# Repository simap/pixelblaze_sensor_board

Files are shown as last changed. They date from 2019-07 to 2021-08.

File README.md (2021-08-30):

Pixelblaze Sensor Expansion Board
-------------------

sensor board

* A microphone and signal processing with frequency magnitude data ranging from 37Hz-10KHz designed to work in very loud environments
* A 3-axis 16G accelerometer
* An ambient light sensor
* 5 analog inputs that can be used with potentiometers or other analog inputs

[For sale on Tindie](https://www.tindie.com/products/12158/)! Pick up this board and/or a Pixelblaze! Make cool sound-reactive LED things, or get one and hack the firmware!

soundmatrix

I hope you find this useful or interesting. Maybe you hack your board? I'd be stoked to hear about it! Roll your own? Great! Turn it into a robot brain? Awesome!

Shout out to Sparkfun, their boards were used in the initial prototype, and their Eagle files were really helpful!

Shout out to [https://github.com/pyrohaz/STM32F0-PCD8544GraphicAnalyzer](https://github.com/pyrohaz/STM32F0-PCD8544GraphicAnalyzer) which does similar FFT stuff with a similar processor, even shares the fixed point FFT code in common!

Non-Pixelblaze Usage
-------------------
Looking to use this with an Arduino or Teensy or something? You just need a free serial port at 115200 baud.

The protocol is fairly simple:

1. Each frame starts with "SB1.0" including a null character (6 bytes).
2. The frequency information follows, as 32 x 16-bit unsigned integers.
3. Then is the audio energy average, max frequency magnitiude, max frequency Hz, all 3 as 16-bit unsigned ints.
4. Next the accelerometer information as 3 x 16-bit signed integers.
5. The data from the Light sensor is next, as a single 16-bit unsigned integer.
6. Followed by the 5 x 16-bit analog inputs (12-bit resolution, shifted up to 16 bits)
7. Finally "END" including a null character (4 bytes).

License Information
-------------------
The hardware files are released under [Creative Commons ShareAlike 4.0 International](https://creativecommons.org/licenses/by-sa/4.0/) since the PCB is largely based off of Sparkfun boards with this license requirement.

Distributed as-is; no warranty is given.

The ElectroMage logo and wizard character is excluded from this license.

The software is released under The MIT License.

The MIT License

Copyright (c) 2018 Ben Hencke

Permission is hereby granted, free of charge, to any person obtaining a copy
of this software and associated documentation files (the "Software"), to deal
in the Software without restriction, including without limitation the rights
to use, copy, modify, merge, publish, distribute, sublicense, and/or sell
copies of the Software, and to permit persons to whom the Software is
furnished to do so, subject to the following conditions:

The above copyright notice and this permission notice shall be included in
all copies or substantial portions of the Software.

THE SOFTWARE IS PROVIDED "AS IS", WITHOUT WARRANTY OF ANY KIND, EXPRESS OR
IMPLIED, INCLUDING BUT NOT LIMITED TO THE WARRANTIES OF MERCHANTABILITY,
FITNESS FOR A PARTICULAR PURPOSE AND NONINFRINGEMENT. IN NO EVENT SHALL THE
AUTHORS OR COPYRIGHT HOLDERS BE LIABLE FOR ANY CLAIM, DAMAGES OR OTHER
LIABILITY, WHETHER IN AN ACTION OF CONTRACT, TORT OR OTHERWISE, ARISING FROM,
OUT OF OR IN CONNECTION WITH THE SOFTWARE OR THE USE OR OTHER DEALINGS IN
THE SOFTWARE.

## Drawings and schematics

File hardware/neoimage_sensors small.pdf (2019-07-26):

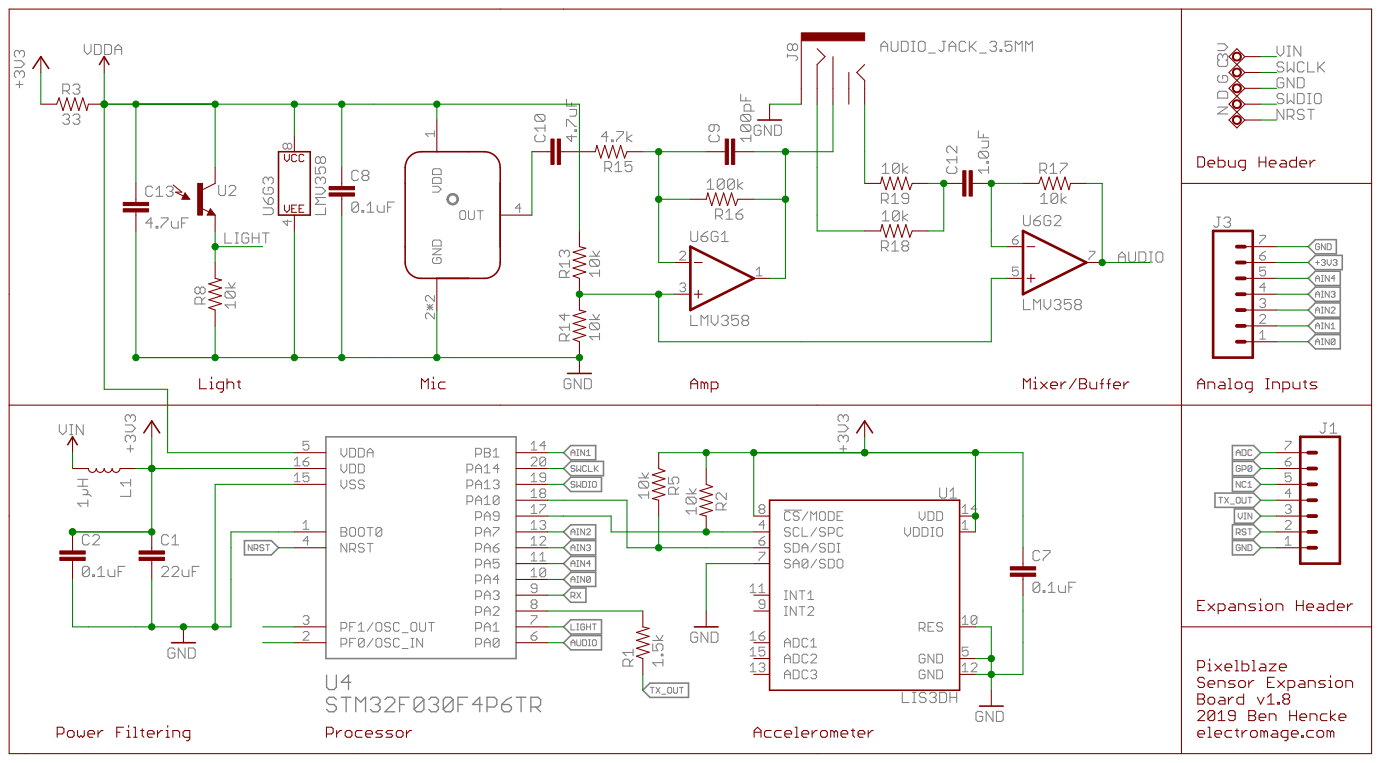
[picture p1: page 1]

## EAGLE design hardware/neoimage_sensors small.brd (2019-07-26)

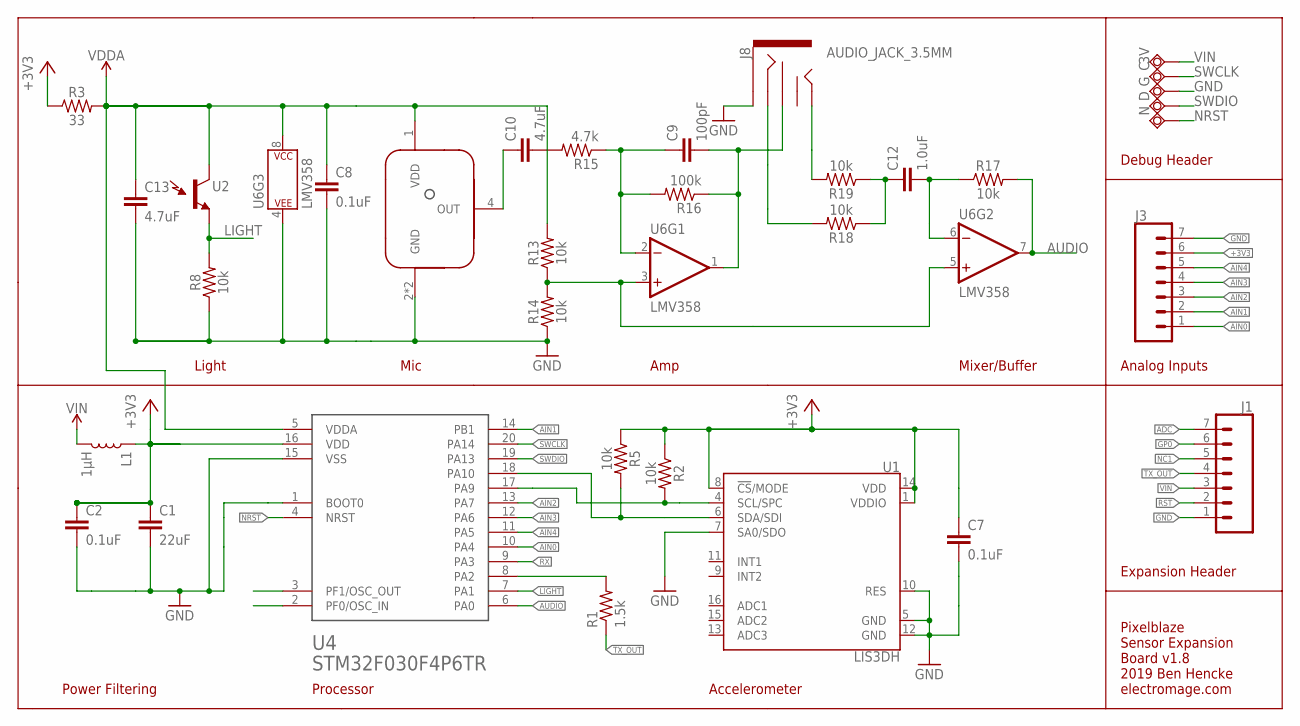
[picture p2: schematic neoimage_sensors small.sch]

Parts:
3V: TPSQTP18SQ; TP18SQ
C: TPSQTP18SQ; TP18SQ
C1: 22uF; 0805
C2, C7, C8: 0.1uF; 0603
C9: 100pF; 0603
C10, C13: 4.7uF; 0603
C12: 1.0uF; 0603
D: TPSQTP18SQ; TP18SQ
G: TPSQTP18SQ; TP18SQ
J1, J3: CONN_07LOCK; 1X07_LOCK
J8: AUDIO_JACK_3.5MM; AUDIO-JACK-KIT
L1: 1µH; 0805
N: TPSQTP18SQ; TP18SQ
R1: 1.5k; 0603
R2, R5, R8, R13, R14, R17, R18, R19: 10k; 0603
R3: 33; 0603
R15: 4.7k; 0603
R16: 100k; 0603
U1: LIS3DH; LGA-16-3X3
U2: LIGHT_SENSORALS; ALS-PT19
U4: STM32F030F4P6TR; TSSOP-20
U6: LMV358; SO08
U$3: MICROPHONE-MEMS; MICROPHONE-MEMS-3X3.75

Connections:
+3V3: C1.1, C2.1, C7.1, J3.6, L1.1, R2.1, R3.1, R5.1, U1.1 (VDDIO), U1.8 (!CS!/MODE), U1.14 (VDD), U4.16 (VDD)
ADC: J1.7
AIN0: J3.1, U4.10 (PA4)
AIN1: J3.2, U4.14 (PB1)
AIN2: J3.3, U4.13 (PA7)
AIN3: J3.4, U4.12 (PA6)
AIN4: J3.5, U4.11 (PA5)
AUDIO: R17.2, U4.6 (PA0), U6.7 (OUT)
GND: C1.2, C2.2, C7.2, C8.2, C13.2, G.TP, J1.1, J3.7, J8.SLEEVE, R8.1, R14.1, U1.5 (GND), U1.7 (SA0/SDO), U1.10 (RES), U1.12 (GND), U4.1 (BOOT0), U4.15 (VSS), U6.4 (P$V-), U$3.2 (GND), U$3.3 (GND)
GP0: J1.6
LIGHT: R8.2, U2.E (E1), U4.7 (PA1)
MICOUT: C9.2, J8.RSH, R16.1, U6.1 (OUT)
unnamed: C10.1, U$3.4 (OUT)
unnamed: C9.1, R15.1, R16.2, U6.2 (-IN)
unnamed: C10.2, R15.2
unnamed: R13.1, R14.2, U6.3 (+IN), U6.5 (+IN)
unnamed: C12.1, R18.1, R19.1
unnamed: C12.2, R17.1, U6.6 (-IN)
unnamed: J8.TIP, R19.2
unnamed: J8.RING, R18.2
NC1: J1.5
NRST: N.TP, U4.4 (NRST)
RST: J1.2
RX: U4.9 (PA3)
SCL: R5.2, U1.6 (SDA/SDI), U4.18 (PA10)
SDA: R2.2, U1.4 (SCL/SPC), U4.17 (PA9)
SWCLK: C.TP, U4.20 (PA14)
SWDIO: D.TP, U4.19 (PA13)
TX: R1.2, U4.8 (PA2)
TX_OUT: J1.4, R1.1
VDDA: C8.1, C13.1, R3.2, R13.2, U2.C (C1), U4.5 (VDDA), U6.8 (P$V+), U$3.1 (VDD)
VIN: 3V.TP, J1.3, L1.2

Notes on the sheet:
Expansion Header
Analog Inputs
Debug Header
Mic
Accelerometer
Processor
Light
Amp
Mixer/Buffer
Power Filtering
Pixelblaze Sensor Expansion Board v1.8 2019 Ben Hencke electromage.com

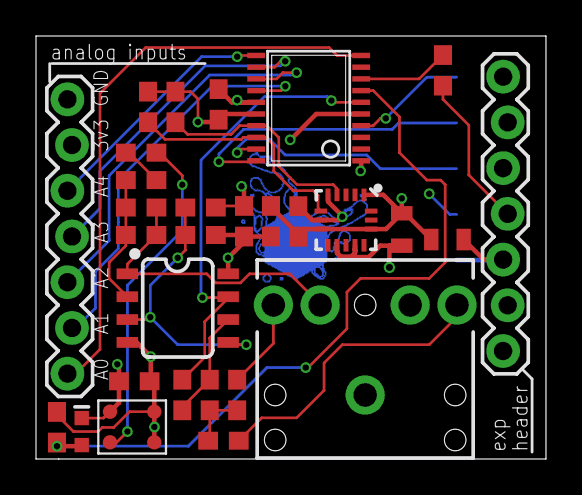
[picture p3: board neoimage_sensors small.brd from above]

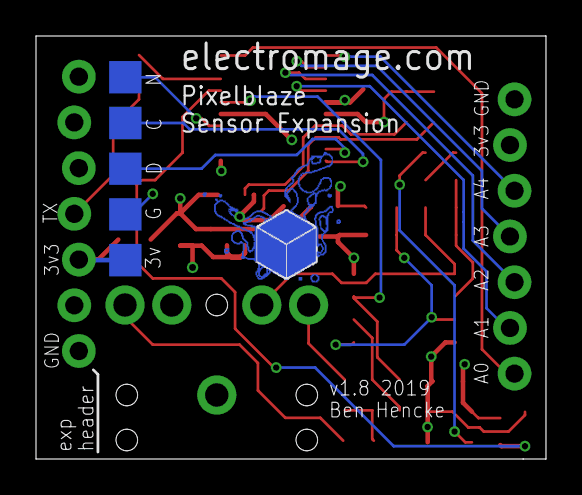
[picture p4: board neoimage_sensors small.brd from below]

Board: 4 copper layers, 28.3 x 23.5 mm, 35 parts (6 on the bottom side), 27 nets.

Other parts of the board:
U$4: ELECTRO_MAGE_PCB4_PIXEL_2#PNG

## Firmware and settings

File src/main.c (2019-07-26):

#include "main.h"


enum {
	IDLE, STARTING, SENDING_REG, READING, STOPPING, NEEDSRESET
} I2CMode = NEEDSRESET;


uint32_t audioAverage = 16384<<16;
volatile uint16_t adcBuffer[7]; //updated by DMA @ 20KHz
volatile int16_t accelerometer[3]; //updated by DMA
volatile uint32_t ms = 0; //updated by SysTick


//ping-pong buffer for main 20KHz audio
volatile bool readDone;
int readSide;
int readPos;
int16_t buffer[2][HIGH_N];

//circular buffer for low frequency stuff - we need to reuse parts of it and can afford the memory
//the 32 samples cover 1600 samples of the original audio
struct {
	int16_t circular[32];
	int16_t output[32];
	int head;
	//keep track of how many samples have passed through the filter to know when to sample from it
	int downSampleCounter;
	int32_t avg;
} bufferLowHz;

int main(void) {
	SysTick_Config(SystemCoreClock/1000); //tick interval 1ms
	initRcc();
	initTim1();
	initDma();
	initAdc();
	initGpio();
	initUart();
	initI2C();

	for (;;) {

		if (I2CMode == NEEDSRESET)
			initAccelerometer();

		//listen for message that the sample buffer is ready to process
		if (readDone) {
			readDone = false;

//			GPIO_WriteBit(GPIOB, GPIO_Pin_1, 1);

			//start polling the accelerometer now, it can run in the background while the FFT processes
			startAccelerometerPoll();

			//grab the side we're not currently writing to and do an FFT on it
			processSensorData(&buffer[!readSide][0], &bufferLowHz.output[0], adcBuffer, accelerometer);

//			GPIO_WriteBit(GPIOB, GPIO_Pin_1, 0);
		}

	}
}

void initRcc() {
	//enable adc, dma, uart, i2c, and gpio clocks
	RCC->AHBENR |= RCC_AHBENR_GPIOAEN | RCC_AHBENR_GPIOBEN | RCC_AHBENR_DMAEN;
	RCC->APB1ENR |= RCC_APB1ENR_I2C1EN;
	RCC->APB2ENR |= RCC_APB2ENR_ADC1EN | RCC_APB2ENR_TIM1EN | RCC_APB2ENR_USART1EN;

	//Start HSI14 RC oscillator for the ADC and wait for it
	RCC->CR2 |= RCC_CR2_HSI14ON;
	while (!(RCC->CR2 & RCC_CR2_HSI14RDY))
		;
}

void initTim1() {
	TIM1->CR2 |= TIM_CR2_MMS_1 | TIM_CR2_MMS_0; //output compare pulse - magic trigger needed for ADC
	TIM1->CR1 |= TIM_CR1_CEN | TIM_CR1_ARPE; // enable and auto-reload
	TIM1->ARR = 2399; //48mhz / 2400 = 20khz

	//Generate an update event to reload the Prescaler and the repetition countervalue immediately
	TIM1->EGR = TIM_EGR_UG;
}

void initAdc() {
	// set ADC_CR_ADCAL to start calibration and wait for it to clear
	ADC1->CR |= ADC_CR_ADCAL;
	while (ADC1->CR & ADC_CR_ADCAL)
		;
	//set ADC_CFGR1_CONT for continuous mode
	//set ADC_CFGR1_EXTEN = 01 for trigger on rising edge
	//set ADC_CFGR1_EXTSEL = 000 for TIM1_TRGO
	//set ADC_CFGR1_DMACFG = 1 for dma circular
	//set ADC_CFGR1_DMAEN = 1 to enable dma
	ADC1->CFGR1 = ADC_CFGR1_DMACFG | ADC_CFGR1_DMAEN | ADC_CFGR1_EXTEN_0;

	//set ADC_SMPR = 101 for 55cycle sample time
	ADC1->SMPR = 0b101;
	//set ADC_CHSELR bits to enable various channels (0, 1, 4, 5, 6, 7, 8)
	ADC1->CHSELR = ADC_CHSELR_CHSEL0 | ADC_CHSELR_CHSEL1 | ADC_CHSELR_CHSEL4 |
					ADC_CHSELR_CHSEL5 | ADC_CHSELR_CHSEL6 | ADC_CHSELR_CHSEL7 | ADC_CHSELR_CHSEL9;
	//set ADC_ADEN to enable adc and wait for ready
	ADC1->CR |= ADC_CR_ADEN;
	while (!(ADC1->ISR & ADC_ISR_ADRDY))
		;
	//set ADC_CR_ADSTART to start (will wait for external trigger in this mode)
	ADC1->CR |= ADC_CR_ADSTART;
}

void initGpio() {
	//select alternate function 1 (usart1) for pin 2 and 3 - on the stm23f040f4 it defaults to TIM15_CH1/TIM15_CH2
	GPIOA->AFR[0] |= 0b0001 << 8 | 0b0001 << 12;
	//select alternate function 4 (i2c1) for pin 9 and 10
	GPIOA->AFR[1] |= 0b0100 << 4 | 0b0100 << 8;
	//set a0, a1, a4, a5, a6, a7 and b1 to analog inputs
	//set a2, a3 as alternate mode (tx, rx) and a9, a10 as alt mode (i2c)
	GPIOA->MODER |= GPIO_MODER_MODER0 | GPIO_MODER_MODER1 |
			GPIO_MODER_MODER2_1 | GPIO_MODER_MODER3_1 | //set up a2 and a3 as alt function (usart1)
			GPIO_MODER_MODER4 | GPIO_MODER_MODER5 | GPIO_MODER_MODER6 | GPIO_MODER_MODER7 |
			GPIO_MODER_MODER9_1 | GPIO_MODER_MODER10_1; //set up a9 and a10 as alt function (i2c)

	GPIOB->MODER |= GPIO_MODER_MODER1;
//	GPIOB->MODER |= GPIO_MODER_MODER1_0; //output for scoping timings
}

void initUart() {
	USART1->BRR = 0x1A1; // example from manual for 115200 @ 48mhz
	//enable tx, and uart, leave everything else 0 for 8N1
	USART1->CR1 = USART_CR1_TE | USART_CR1_UE;
	//enable DMA for transmits
	USART1->CR3 |= USART_CR3_DMAT;
}

void initDma() {
	//configure DMA to read from ADC into a buffer
	DMA1_Channel1->CPAR = (uint32_t) (&(ADC1->DR)); //point dma to ADC data reg
	DMA1_Channel1->CMAR = (uint32_t) (adcBuffer); //point DMA to buffer memory
	DMA1_Channel1->CNDTR = 7; //count of transfers per circle
	//enable DMA_CCR_CIRC (circular) mode (so addresses reset when its done)
	//set DMA_CCR_MINC to incrememnt memory address
	//set DMA_CCR_MSIZE = 01 for 16 bit xfers to memory
	//set DMA_CCR_PSIZE = 01 for 16 bit xfers from perepheral
	//set DMA_CCR_TCIE for transfer complete interrupt
	DMA1_Channel1->CCR |= DMA_CCR_CIRC | DMA_CCR_MINC | DMA_CCR_MSIZE_0 | DMA_CCR_PSIZE_0 | DMA_CCR_TCIE;
	DMA1_Channel1->CCR |= DMA_CCR_EN; //enable channel 1 dma

	NVIC_EnableIRQ(DMA1_Channel1_IRQn);
	NVIC_SetPriority(DMA1_Channel1_IRQn, 0);

	//NOTE DMA channel2 is used on the fly by sendOutBuffer()

	//configure DMA to read from ADC into a buffer
	DMA1_Channel3->CPAR = (uint32_t) (&(I2C1->RXDR)); //point dma to rx data reg
	DMA1_Channel3->CMAR = (uint32_t) (&accelerometer[0]); //point DMA to buffer memory
	DMA1_Channel3->CNDTR = 6; //count of transfers per circle
	//enable DMA_CCR_CIRC (circular) mode (so addresses reset when its done)
	//set DMA_CCR_MINC to incrememnt memory address
	//set DMA_CCR_TCIE for transfer complete interrupt
	DMA1_Channel3->CCR |= DMA_CCR_CIRC | DMA_CCR_MINC | DMA_CCR_TCIE;
	DMA1_Channel3->CCR |= DMA_CCR_EN; //enable channel 1 dma

	NVIC_EnableIRQ(DMA1_Channel2_3_IRQn);
	NVIC_SetPriority(DMA1_Channel2_3_IRQn, 0);

}

void initI2C() {
	I2C1->TIMINGR = (uint32_t) 0x0000020B; //magic value from cubemx for 400khz
	//enable the module and interrupts for any error condition
	I2C1->CR1 = I2C_CR1_PE | I2C_CR1_ERRIE | I2C_CR1_STOPIE | I2C_CR1_NACKIE | I2C_CR1_RXDMAEN;

	NVIC_EnableIRQ(I2C1_IRQn);
	NVIC_SetPriority(I2C1_IRQn, 4);
}


void writeToUsart(uint8_t * outBuffer, uint32_t len) {
	DMA1_Channel2->CCR = 0; //disable, reset state
	DMA1_Channel2->CPAR = (uint32_t) &USART1->TDR;
	DMA1_Channel2->CMAR = (uint32_t) outBuffer;
	DMA1_Channel2->CNDTR = len;
	//set DMA_CCR_MINC to increment mem address
	//set DMA_CCR_DIR for out to perepheral
	//set DMA_CCR_EN to make it so
	DMA1_Channel2->CCR = DMA_CCR_MINC | DMA_CCR_DIR | DMA_CCR_EN;
}

//write a single value to a register. Slow, blocking, but usually only used during startup
//TODO could be more resilient to transient i2c errors. If things go really sideways this will just block forever
void i2cWriteReg(uint8_t addr, uint8_t reg, uint8_t value) {
	while (I2C1->ISR & I2C_ISR_BUSY)
		;
	//initiate start, send out slave address
	I2C_TransferHandling(I2C1, addr, 2, I2C_SoftEnd_Mode, I2C_Generate_Start_Write);
	//wait for TXIS
	while (I2C_GetFlagStatus(I2C1, I2C_ISR_TXIS) == 0)
		;
	//write out register address of interest
	I2C_SendData(I2C1, reg);
	while (I2C_GetFlagStatus(I2C1, I2C_ISR_TXIS) == 0)
		;
	I2C_SendData(I2C1, value);
	//wait for TC
	while (I2C_GetFlagStatus(I2C1, I2C_ISR_TC) == 0)
		;
	I2C_GenerateSTOP(I2C1, ENABLE);
}

void i2cReadReg(uint8_t addr, uint8_t reg, uint8_t * value, uint8_t len) {
	while (I2C1->ISR & I2C_ISR_BUSY)
		;
	//initiate start, send out slave address
	I2C_TransferHandling(I2C1, addr, 1, I2C_SoftEnd_Mode, I2C_Generate_Start_Write);
	//wait for TXIS
	while (I2C_GetFlagStatus(I2C1, I2C_ISR_TXIS) == 0)
		;
	//write out register address of interest
	I2C_SendData(I2C1, reg | 0x80);
	//wait for TC
	while (I2C_GetFlagStatus(I2C1, I2C_ISR_TC) == 0)
		;
	I2C_TransferHandling(I2C1, LIS3DH_ADDR, len, I2C_AutoEnd_Mode, I2C_Generate_Start_Read);

	for (int i = 0; i < len; i++) {
		//wait for RXNE
		while (I2C_GetFlagStatus(I2C1, I2C_ISR_RXNE) == 0)
			;
		value[i] = I2C_ReceiveData(I2C1);
	}

	while (I2C1->ISR & I2C_ISR_BUSY)
		;
}

void initAccelerometer() {
	I2C1->CR1 = I2C_CR1_PE | I2C_CR1_ERRIE | I2C_CR1_STOPIE | I2C_CR1_NACKIE | I2C_CR1_RXDMAEN;
	//configure registers for desired mode
	//set CTRL_REG1(20h) - ODR 100hz = 0101 | lpen off = 0 | xzy enable = 111
	i2cWriteReg(LIS3DH_ADDR, 0x20, 0b01010111);
	//set CTRL_REG4(23h) - BDU continuous = 1 | BLE big = 0 | FS 16g = 11 | HR high = 1 | ST off = 00 | SIM x = 0
	i2cWriteReg(LIS3DH_ADDR, 0x23, 0b10111000);
	I2CMode = IDLE;
}

//start poll sequence by initiating a start and sending the slave address
void startAccelerometerPoll() {
	//check to see if things are in the right state for this, or make it so
	//maybe something went wrong, and we can reset things back to normal.
	if (I2CMode == IDLE) {
		I2C_TransferHandling(I2C1, LIS3DH_ADDR, 1, I2C_SoftEnd_Mode, I2C_Generate_Start_Write);
		I2CMode = STARTING;
		I2C1->CR1 |= I2C_CR1_TXIE; //listen for TXIS, indicating that we can start writing
	} else {
		I2CMode = NEEDSRESET;
	}
}


void SysTick_Handler(void) {
	//keep track of milliseconds
	ms++;
}

//handle DMA for the channel doing ADC
void DMA1_CH1_IRQHandler() {
	if (DMA1->ISR & DMA_ISR_TCIF1) {
		//the dma transfer is complete
		int16_t audioSample = adcBuffer[0]<<3;


		//downsample 50:1 for the low frequency buffer
		bufferLowHz.avg += audioSample;
		if (++bufferLowHz.downSampleCounter >= 50) {
			bufferLowHz.downSampleCounter = 0;
			bufferLowHz.circular[bufferLowHz.head++] = bufferLowHz.avg/50 - (audioAverage>>16);
			bufferLowHz.avg = 0;
			if (bufferLowHz.head >= 32)
				bufferLowHz.head = 0;
		}

		volatile int32_t d = (audioSample<<16) - audioAverage;
		audioAverage += (d) >> 16;
		audioSample -= audioAverage>>16;


		//save to the ping-pong buffer
		buffer[readSide][readPos] = audioSample;

		readPos++;
		if (readPos >= HIGH_N) {
			//copy the 400 hz buffer snapshot
			for (int i = 0; i < LOW_N; i++) {
				bufferLowHz.output[i] = bufferLowHz.circular[(bufferLowHz.head + i) & 31];
			}
			//toggle sides and mark done
			readSide = !readSide;
			readPos = 0;
			readDone = true;
		}
	}

	//is this bad? this seems right, but also wrong somehow
	//unset any set bits for channel1
	DMA1->IFCR = DMA1->ISR & 0xf;
}


void I2C1_ErrorHandler() {
	I2CMode = NEEDSRESET;
	I2C_GenerateSTOP(I2C1, ENABLE);
}

void I2C1_IRQHandler() {
	if (I2C1->ISR & (I2C_ISR_NACKF | I2C_ISR_ARLO | I2C_ISR_BERR)) {
		I2C1_ErrorHandler();
	} else {
		switch (I2CMode) {
		case STARTING:
			//expect I2C_ISR_TXIS
			if (!(I2C1->ISR & I2C_ISR_TXIS)) {
				I2C1_ErrorHandler();
				break;
			}
			I2CMode = SENDING_REG;
			I2C_SendData(I2C1, 0x28 | 0x80); //start at OUT_X_L and set MSB to increment per read
			I2C1->CR1 &= ~I2C_CR1_TXIE; //ignore TXIS for now
			I2C1->CR1 |= I2C_CR1_TCIE; //listen for TC

			break;
		case SENDING_REG:
			//expect I2C_ISR_TC
			if (!(I2C1->ISR & I2C_ISR_TC)) {
				I2C1_ErrorHandler();
				break;
			}
			I2CMode = READING;
			I2C_TransferHandling(I2C1, LIS3DH_ADDR, 6, I2C_AutoEnd_Mode, I2C_Generate_Start_Read);
			I2C1->CR1 &= ~I2C_CR1_TCIE; //ignore TC for now, waiting for DMA
			break;
		case READING:
			//DMA is handling the reads, so if we get here there's probably an error
			I2C1_ErrorHandler();
			break;
		case STOPPING:
			//expect I2C_ISR_STOPF
			if (!(I2C1->ISR & I2C_ISR_STOPF)) {
				I2C1_ErrorHandler();
				return;
			}
			I2CMode = IDLE;
			break;
		case IDLE:
			//don't care really
			break;
		case NEEDSRESET:
			//can't do much here
			break;
		}
	}

	I2C1->ICR = I2C1->ISR; //is this bad? this seems right, but also wrong somehow
}

//handle DMA for the channel doing I2C
void DMA1_CH2_3_IRQHandler() {
	if (DMA1->ISR & DMA_ISR_TCIF3) {
		//i2c transfer complete
		I2CMode = STOPPING;
	}
	//is this bad? this seems right, but also wrong somehow
	//unset any set bits for channel3
	DMA1->IFCR = DMA1->ISR & 0xf00;
}

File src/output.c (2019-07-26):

#include "main.h"

//an fft of 512 gives us 256 buckets of frequency info. at 20khz, each has ~38Hz
//we don't really want all 256 buckets of frequency info
//if we compressed this linearly, we'd lose a lot of low/mid tone info
//also, in order to capture low frequency stuff below 38Hz would require a much larger fft
//so we can combine a downsampled 400hz using a smaller fft for low frequency stuff with the 20khz stuff

//the first 6 buckets are dedicated to low frequency audio from 12.5-162.5 Hz
const uint8_t lowFrequencyMap[6] = {
		3, 4, 6, 8, 10, 13
};
//the next 26 buckets are dedicated to higher frequency audio from 195Hz to just under the nyquist limit of 10khz
const uint8_t highFrequencyMap[26] = {
		5, 6, 8, 10, 12, 15, 18, 22, 25, 30, 35, 40, 46, 53, 61, 70, 80, 92, 105, 119, 136, 154, 175, 199, 225, 255,
};


char outBuffer[100];
int outBufferLen;

#define WRITEOUT(v) {memcpy(out, &v, sizeof(v)); out+= sizeof(v);}

/*
 * Takes a real input, applies Hann window, calculates energyAverage
 * out must be the the same size as in as it is used for the imaginary part
 * after returning, the first half is filled with bucket magnitudes
 * magnitude is multiplied by 16 and saturates at 16 bits
 * m = log2(n)
 */
void fftRealWindowedMagnitude(int16_t * in, uint16_t * out, int m, uint16_t * energyAverage) {
	int16_t * imag = (int16_t *) out; //borrow out for imaginary part
	int n = 1 << m;

	//init with zeros
	for (int i = 0; i < n; i++) {
		imag[i] = 0;
	}
	uint32_t energyTotal = 0;
	for (int i = 0; i < n; i++) {
		energyTotal += abs(in[i]);

		//apply the hann windowing function, borrowing Sinewave LUT from fix_fft
		//the positive portion of Sinewave ranges from index 0-512
		// (i * 512) / n  == (i * 512) >> m
		int si = (i * 512) >> m ;
		in[i] = (Sinewave[si] * in[i]) >> 16;
	}
	*energyAverage = energyTotal >> m;

	//run the FFT (runs in place, overwriting both in and imag)
	fix_fft(in, imag, m, 0);

	//calculate the magnitude and store in out for only the first half
	int halfN = n>>1;
	for (int i = 0; i < halfN; i++) {
		//using the fix16_sqrt gives us a bit more resolution as we get
		//8 bits more using this over an integer sqrt
		int32_t t = fix16_sqrt(imag[i] * imag[i] + in[i] * in[i]);

		//we can't keep all those extra bits, but 4 of 8 seems like a good value
		//as this only overloads a little and only for REALLY LOUD inputs
		t >>= 4;
		if (t > 0xffff)
			t = 0xffff;
		out[i] = t;
	}
}

void processSensorData(int16_t * audioBuffer, int16_t * audio400HzBuffer, volatile uint16_t adcBuffer[7], volatile int16_t accelerometer[3]) {
	uint16_t magnitude[HIGH_N]; //temp and output from the fft
	uint16_t lowEnergy;
	uint16_t energyAverage;
	int maxFrequencyIndex = 0;
	uint16_t maxFrequencyMagnitude = 0;
	uint16_t maxFrequencyHz;
	char * out = outBuffer;

	//start making output buffer
	WRITEOUT("SB1.0");

	//do the low frequency stuff
	fftRealWindowedMagnitude(audio400HzBuffer, &magnitude[0], LOW_NLOG2, &lowEnergy);
	//write out low frequency stuff
	for (int i = 0, k = lowFrequencyMap[0]; i < 6; i++) {
		int top = lowFrequencyMap[i] + 1;
		uint16_t max = 0;
		for (; k < top; k++) {
			max = magnitude[k] > max ? magnitude[k] : max;
		}
		WRITEOUT(max);
	}

	//do high frequency stuff
	fftRealWindowedMagnitude(audioBuffer, &magnitude[0], HIGH_NLOG2, &energyAverage);

	//run through and get maxFrequency info
	for (int i = 1; i < HIGH_N/2; i++) {
		if (magnitude[i] > maxFrequencyMagnitude) {
			maxFrequencyMagnitude = magnitude[i];
			maxFrequencyIndex = i;
		}
	}

	//write out high frequency stuff
	for (int i = 0, k = highFrequencyMap[0]; i < 26; i++) {
		int top = highFrequencyMap[i] + 1;
		uint16_t max = 0;
		for (; k < top; k++) {
			max = magnitude[k] > max ? magnitude[k] : max;
		}
		WRITEOUT(max);
	}

	WRITEOUT(energyAverage);
	WRITEOUT(maxFrequencyMagnitude);
	maxFrequencyHz = (20000 * (int32_t)maxFrequencyIndex) / 512; //or 39.0625 per bin
	WRITEOUT(maxFrequencyHz);

	for (int i = 0; i < 3; i++) {
		int16_t v = accelerometer[i];
		WRITEOUT(v);
	}

	//light
	uint16_t v = adcBuffer[1]<<4;
	WRITEOUT(v);

	//a0
	v = adcBuffer[2]<<4;
	WRITEOUT(v);
	//a1
	v = adcBuffer[6]<<4;
	WRITEOUT(v);
	//a2
	v = adcBuffer[5]<<4;
	WRITEOUT(v);
	//a3
	v = adcBuffer[4]<<4;
	WRITEOUT(v);
	//a4
	v = adcBuffer[3]<<4;
	WRITEOUT(v);


	WRITEOUT("END");

	outBufferLen = out - outBuffer;
	writeToUsart((uint8_t *) outBuffer, outBufferLen);
}

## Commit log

2018-02-24 initial
    works, I think!
    Timer triggers ADC, DMA collects. Store into ping-pong buffer
    FFT that, calculate magnitude.
    Hacked some efficiency - removed stdclib which freed up 1k ram (wtf?)
    just init registers directly, HAL and other drivers are quite bloated.
    [sensorsRaw Run.cfg]
2018-02-28 compress fft buckets using exponential curve, accelerometer
2018-03-13 add another fft for low frequency stuff, refactor lots
    downsample the 20khz to 400hz and run that through fft to get
    more depth around 12.5-162.5hz range
    tried a bunch of digital filters on downsampling, but didn't seem to
    make a difference in aliasing. simple average works about the same.
    [main.c, output.c]
2018-03-13 remove ref to the iir filter
2018-04-15 simplify downsampler, bug in maxfrequency stuff
    [main.c, output.c]
2018-05-12 board files
    [neoimage_sensors small.brd, neoimage_sensors small.sch]
2019-07-16 v1.8 of board
    switch to 0603, fix analog, labels
    [neoimage_sensors small.brd, neoimage_sensors small.sch]
2019-07-26 switch analog input order
2019-07-26 labels for panel
    [neoimage_sensors small.brd]
2019-07-26 cleanup schematic, name signals, pdf
    [neoimage_sensors small.brd, neoimage_sensors small.sch]
2021-08-28 Add light sensor data to description of protocol
    The written description of the serial protocol was missing the information for the analog light sensor - this adds a new line to include it, as specified in the source code.
2022-07-06 add in a few more IDE files after upgrading to stm32cubeIDE

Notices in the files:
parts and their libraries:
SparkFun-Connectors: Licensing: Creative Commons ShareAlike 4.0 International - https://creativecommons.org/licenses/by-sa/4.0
